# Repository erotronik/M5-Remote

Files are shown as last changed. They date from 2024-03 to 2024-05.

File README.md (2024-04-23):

# M5 REMOTE

Please note that this is a modification of the OSSM-M5-Remote project by Ortlof, which is available at [https://github.com/ortlof/OSSM-M5-Remote](https://github.com/ortlof/OSSM-M5-Remote).

Also note that this is an early prototype that is not tested.

This modified project adds RGB Rotary encoders that can light the knobs, and allows the installation of an LED in the push-button.

Furthermore, communication with the board is switched to I2C, using a PWM controller for the LEDs and a port expander for the Rotary encoders. Note that this means that this modification is *not compatible* with the software written for the original OSSM M5 Remote. Currently, there only is a skeleton project [that sketches how to interface with the components on the board in the Firmware folder](./Firmware).

The modified PCB design can be found in the `Hardware/PCB` folder.

The remaining folders in this project are unchanged - please note that the software contained in this repository will not work with the changed hardware.

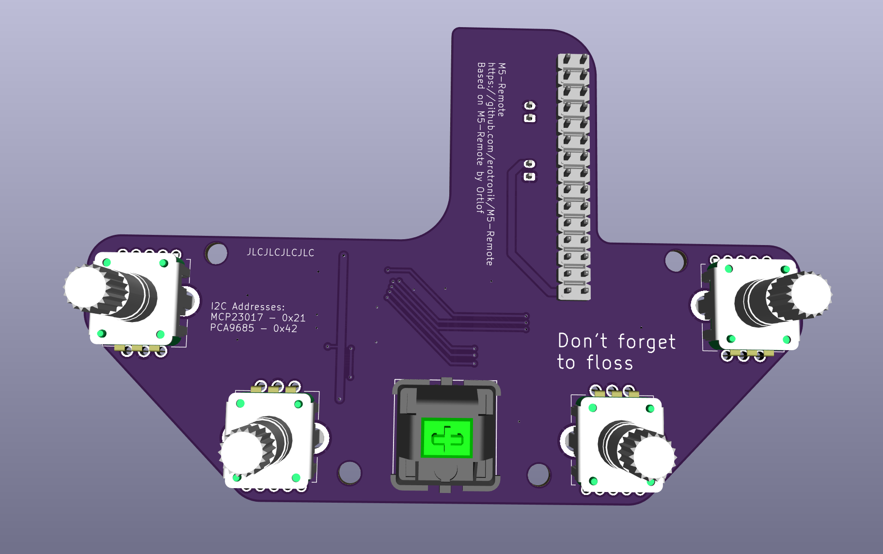
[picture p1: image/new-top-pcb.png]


## Overview of the M5-Remote

The M5 Remote is a remote control platform, e.g. for Sex Toys, or estim devices.

The original project was developed for the OSSM project (https://github.com/KinkyMakers/OSSM-hardware).

This modified version currently does not have direct support for any toys, and requires you to write your own software.

To help with development and design join the KinkyMakers Discord: https://discord.gg/MmpT9xE . Be sure to say hello in the #m5-remote channel. 

# Build the M5 Remote Yourself

## PCB from JLCPCB

The PCB is designed to be made using the JLCPCB assembly service.

To order the PCB, go to [JLCPCP](https://jlcpcb.com) and upload the gerber zip contained in `PCB/jlcpcb`. Leave all settings at default - you can change the PCB colour if you want.

Enable "PCB" assembly, and choose "assemble bottom side" (not selected by default).

In the next step, upload `bom.csv` and `positions.csv`. Verify that the positioning of the components looks corerct before ordering.

## Bill Of Materials for sourcing Electrical Components

BOM is on Octopart for Easy Sourcing: https://octopart.com/bom-tool/pqx0O8QI

## Additional parts needed that are not found on Octopart:

Note - instead of the Kailh switches from pimoroni, any Cherry-compatible switch with LED hole can be used.

| Quantity | Part | Sourcing EU | Price € |
|---|---|---|---|
| 1x | Switch | https://shop.pimoroni.com/products/kailh-mechanical-switches-pack-of-12?variant=32056315314259 | 7
| 2x | M3x25mm Hex Head Cap Bolt | https://www.amazon.de/Edelstahl-Innensechskant-Bolzenset-Eisenrahmen-Mechanischer-Innensechskantschraube-Mutternset/dp/B07PPFT871/ | 12,97 € |
| 4x | M3x20mm Hex Head Cap Bolt | Comes as part of the set mentioned above | " | 
| 4x | Heat Set inserts M3 | https://www.amazon.de/ruthex-Gewindeeinsatz-St%C3%BCck-Gewindebuchsen-Kunststoffteile/dp/B08BCRZZS3 | 8,99 € |
| 1x | 3,7v 2000mAh Lipo Batterie Size 34,5 mm x 10,6 mm x 56 mm | https://www.amazon.de/EEMB-103454-2AhLithium-Schutzplatine-Isolationsbeschichtung/dp/B08214DJLJ/ | 14,89 € |

--------------------------------------------

| Quantity | Part | Sourcing US | Price $ |
|---|---|---|---|
| 2x | M3x25mm Hex Head Cap Bolt | https://www.amazon.com/dp/B09NR8X2LV | $17.99 |
| 4x | M3x20mm Hex Head Cap Bolt | Comes as part of the set mentioned above | " | 
| 4x | Heat Set inserts M3 | https://www.amazon.com/ruthex-M3-Threaded-Inserts-RX-M3x5-7/dp/B08BCRZZS3 | $10.99 |
| 1x | 3.7v 2000mAh Lipo Battery Size 34.5 X 56 X 10.6 mm (The wires will need to be reversed in the connector on this one! See Assembly instructions for more info.) | https://www.amazon.com/EEMB-2000mAh-Battery-Rechargeable-Connector/dp/B08214DJLJ/ | $14.99 |

## 3D Printed Parts Needed:

| Quantity | Part | Information |
|---|---|---|
| 1x | Bottom.stl or Bottom_Adafruit_LIPO.stl or Bottom-Magnets.stl| There is a specific version for the wider Adafruit LIPO battery. Print with the base side facing down, 6 walls 20% Infill | 
| 1x | TOP-*-Keycap-Standoff.stl | Top Depends on your Keycap: Cherry or DSA (DSA is wider) | 
| 4x | M5_Remote_Knob_Customizable.scad | If you go for the 3d Printed knobs |

Filament - A good quality PLA works well. While there are no threads it is recommended that your printer is well calibrated.  

# [Assembly instructions](Assembly.md)

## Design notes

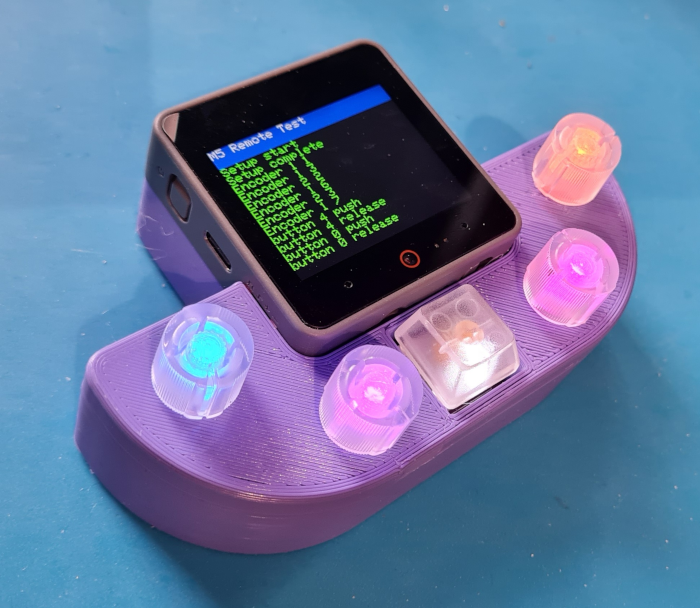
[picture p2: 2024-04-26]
image/remote.png

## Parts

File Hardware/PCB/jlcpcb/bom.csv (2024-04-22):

Designator | Footprint | Quantity | Value | LCSC Part #
C1, C2 | 0402 | 2 | 100n | C1525
R1, R10, R11, R13, R14, R15, R17, R2, R3, R5, R6, R7, R9 | 1206 | 13 | 120R | C17909
R12, R16, R18, R19, R4, R8 | 1206 | 6 | 4k7 | C17936
U1 | TSSOP-28_4.4x9.7mm_P0.65mm | 1 | PCA9685PW | C2678753
U2 | SSOP-28_5.3x10.2mm_P0.65mm | 1 | MCP23017_SS | C506653

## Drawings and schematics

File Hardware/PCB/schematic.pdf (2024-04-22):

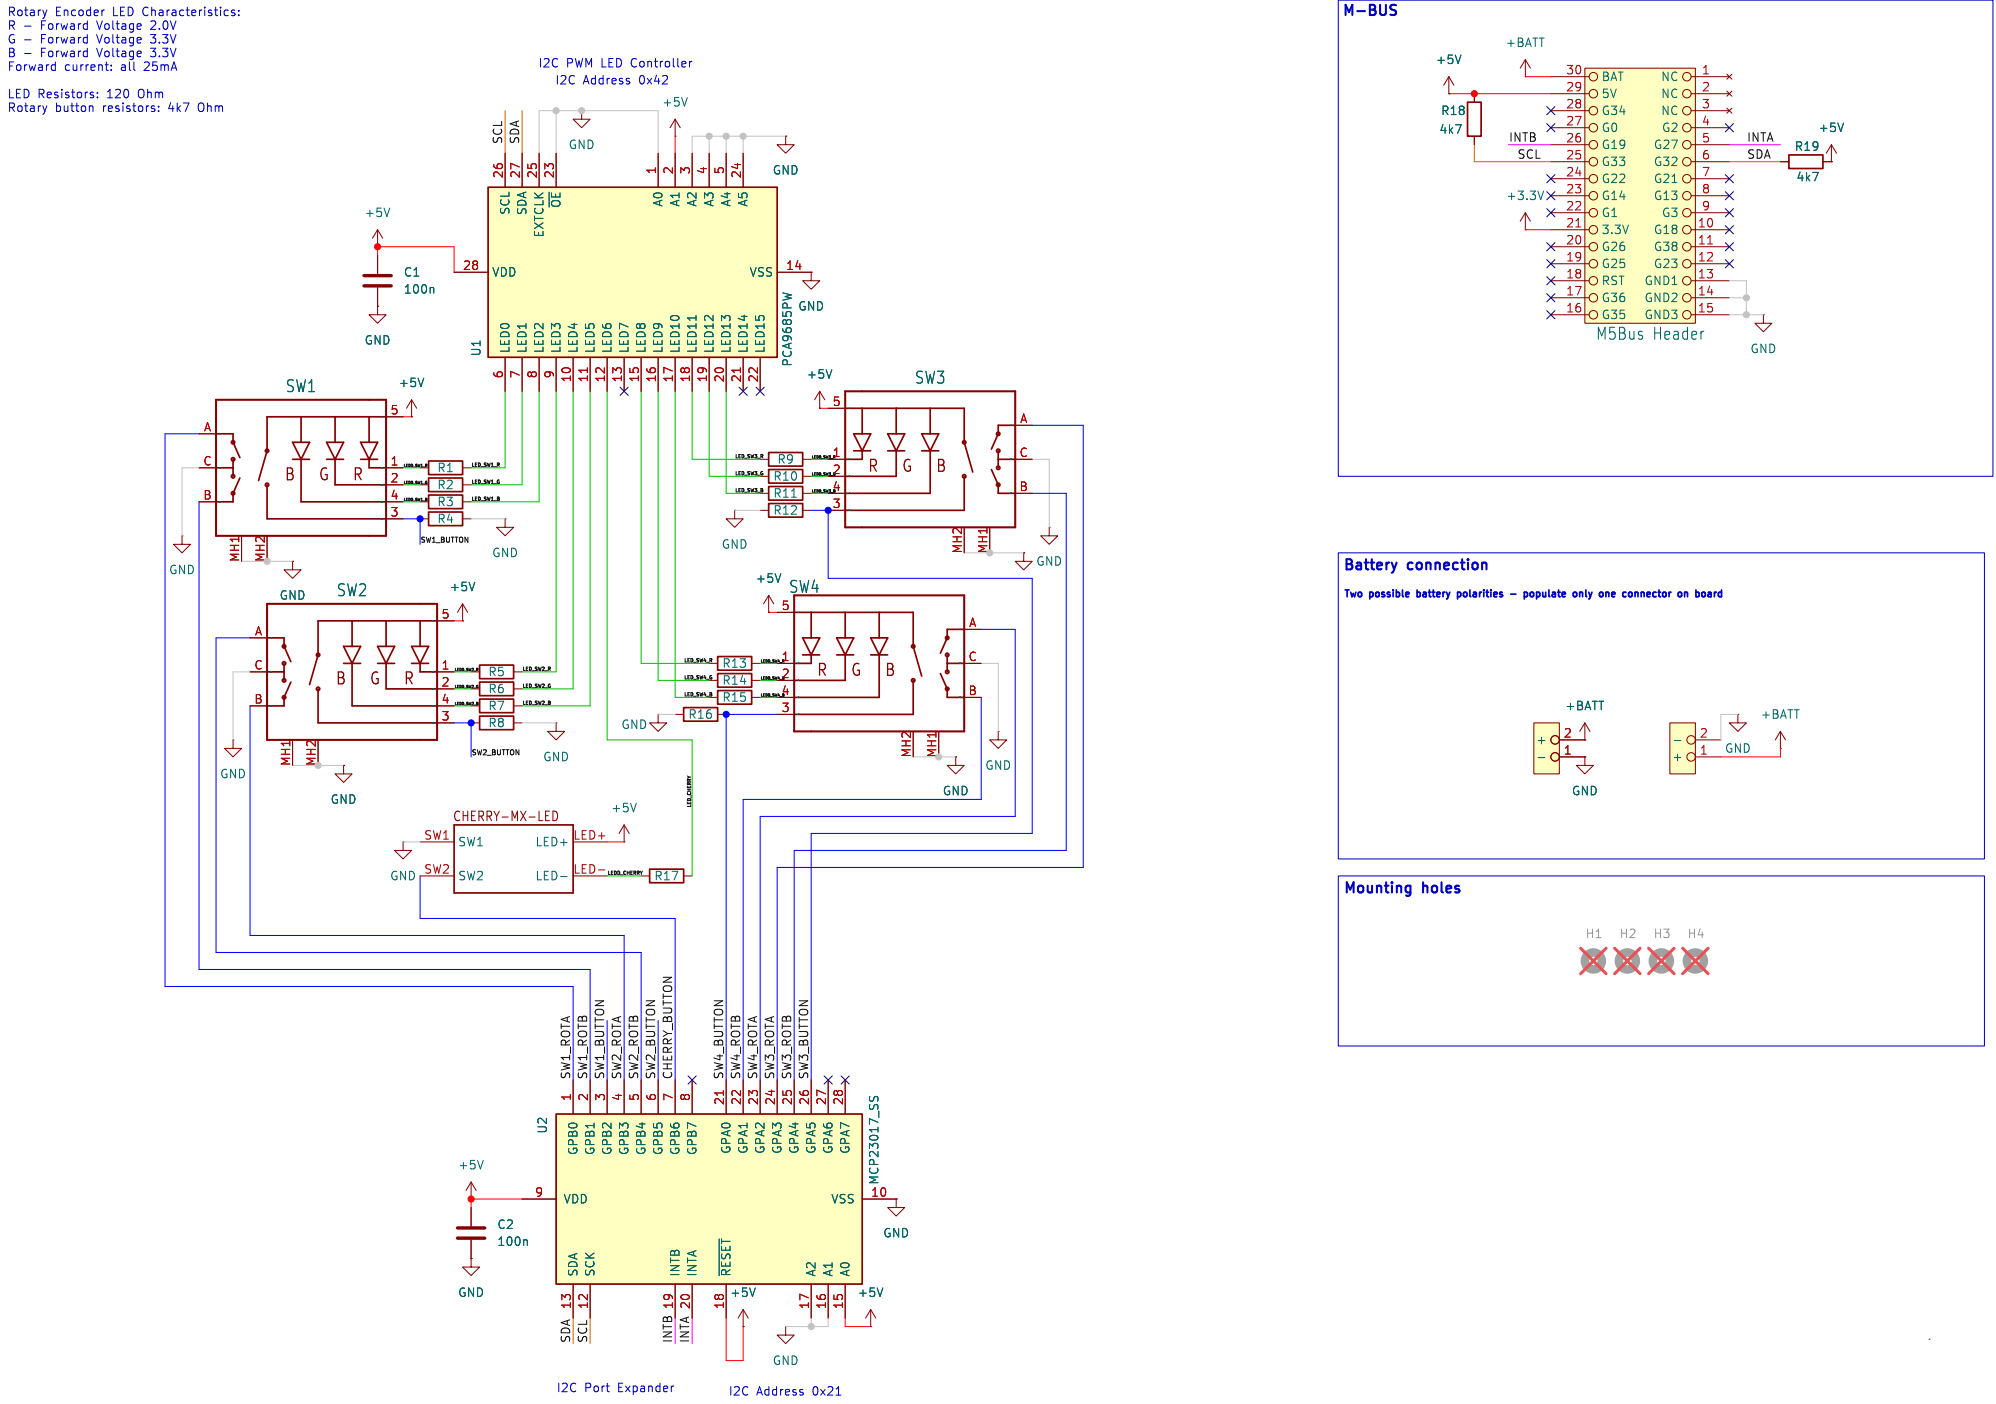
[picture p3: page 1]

Rotary Encoder LED Characteristics: R - Forward Voltage 2.0V G - Forward Voltage 3.3V
+5V GND

2 LED13 20 LED14 21 LED15 22 ~{OE}23 A5 24 EXTCLK 25 SCL 26 SDA 27 VDD 28 A2

1 VSS 10 SCK 12 SDA 13 A0 15 A1 16 A2 17 ~{RESET} 18 INTB 19 GPB1

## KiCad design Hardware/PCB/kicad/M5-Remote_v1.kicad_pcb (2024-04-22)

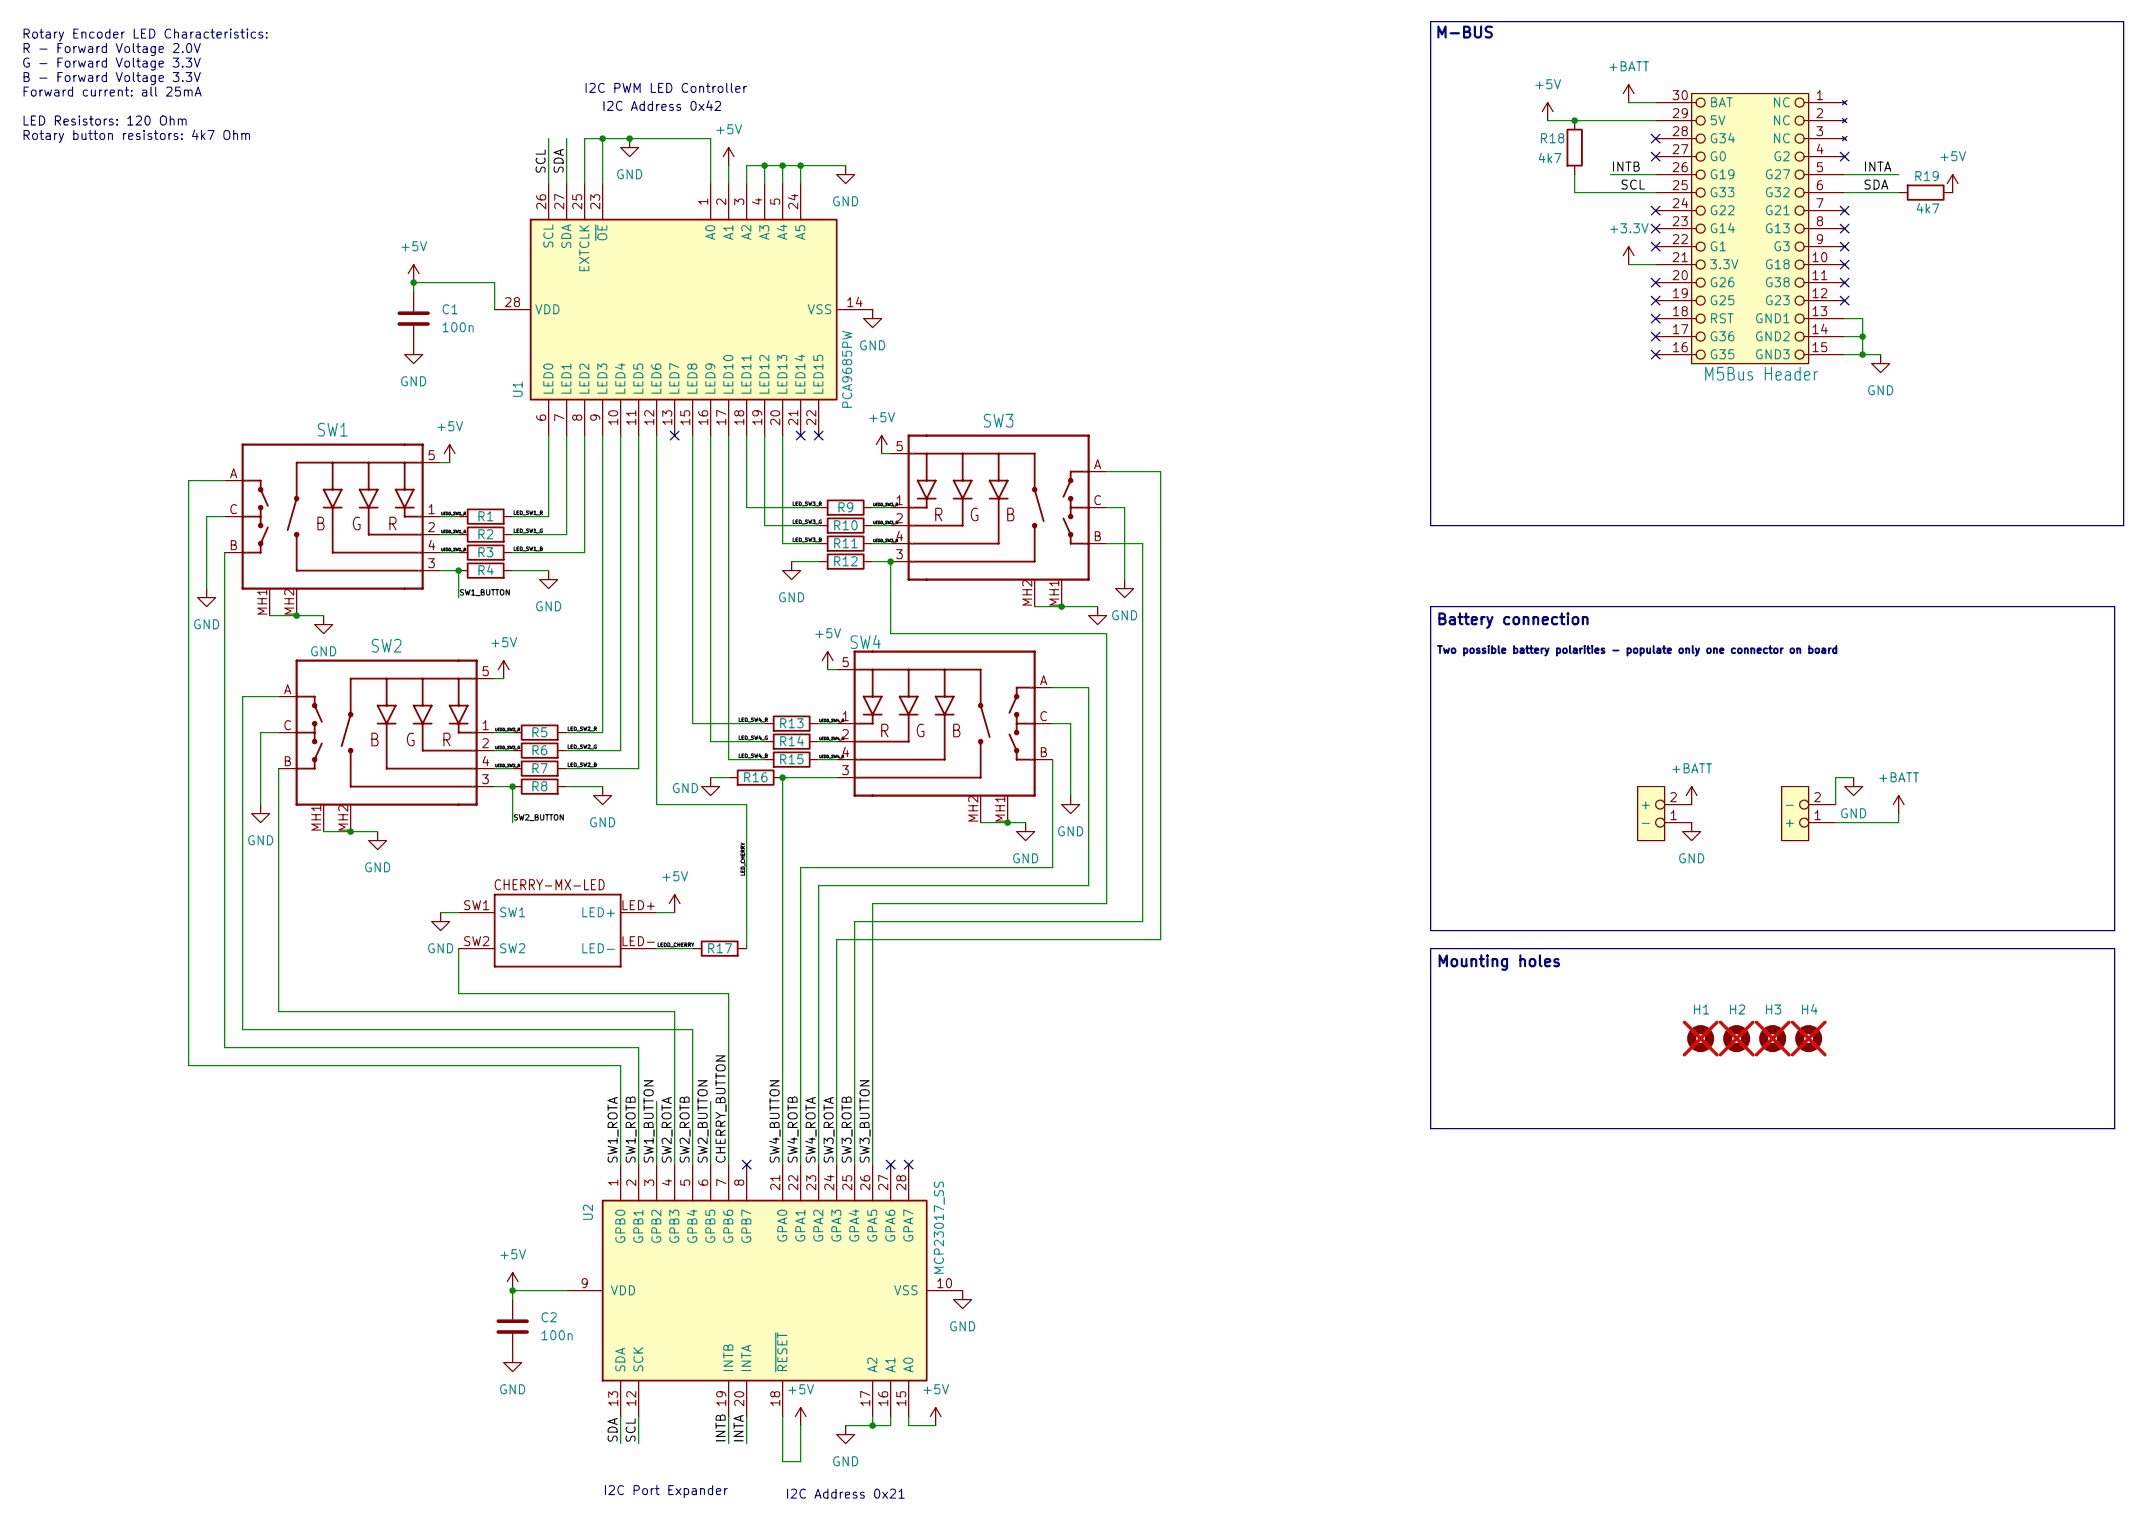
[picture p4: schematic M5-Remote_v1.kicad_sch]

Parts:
B1, B2: JST-PH-2MM,180; JST_PH_S2B-PH-K_1x02_P2.00mm_Horizontal
C1, C2: 100n; C_0402_1005Metric; MFR Part Number CL05B104KO5NNNC; LCSC Part # C1525
H1, H2, H3, H4: MountingHole; mounting_hole_3.3mm; not fitted
M5-CORE2: M5Bus Header; M5_CORE2; MFR Part Number 10129381-930001BLF
R1, R2, R3, R5, R6, R7, R9, R10, R11, R13, R14, R15, R17: 120R; R_1206_3216Metric; MFR Part Number 1206W4F1200T5E; LCSC Part # C17909
R4, R8, R12, R16, R18, R19: 4k7; R_1206_3216Metric; MFR Part Number 1206W4F4701T5E; LCSC Part # C17936
SW1, SW2, SW3, SW4: PEL12T4225SS1024; MFR Part Number PEL12T4225SS1024
U1: PCA9685PW; TSSOP-28_4.4x9.7mm_P0.65mm; MFR Part Number PCA9685; LCSC Part # C2678753
U2: MCP23017_SS; SSOP-28_5.3x10.2mm_P0.65mm; MFR Part Number MCP23017-E/SS; LCSC Part # C506653
U3: CHERRY-MX-LED

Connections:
+3.3V: M5-CORE2.21 (3.3V)
+5V: C1.1, C2.1, M5-CORE2.29 (5V), R18.1, R19.1, SW1.5 (+), SW2.5 (+), SW3.5 (+), SW4.5 (+), U1.2 (A1), U1.28 (VDD), U2.9 (VDD), U2.15 (A0), U2.18 (~RESET), U3.LED+
+BATT: B1.2 (+), B2.1 (+), M5-CORE2.30 (BAT)
/CHERRY_BUTTON: U2.7 (GPB6), U3.SW2
/INTA: M5-CORE2.5 (G27), U2.20 (INTA)
/INTB: M5-CORE2.26 (G19), U2.19 (INTB)
/LEDD_CHERRY: R17.1, U3.LED-
/LEDD_SW1_B: R3.1, SW1.4 (-B)
/LEDD_SW1_G: R2.1, SW1.2 (-G)
/LEDD_SW1_R: R1.1, SW1.1 (-R)
/LEDD_SW2_B: R7.1, SW2.4 (-B)
/LEDD_SW2_G: R6.1, SW2.2 (-G)
/LEDD_SW2_R: R5.1, SW2.1 (-R)
/LEDD_SW3_B: R11.1, SW3.4 (-B)
/LEDD_SW3_G: R10.1, SW3.2 (-G)
/LEDD_SW3_R: R9.1, SW3.1 (-R)
/LEDD_SW4_B: R15.1, SW4.4 (-B)
/LEDD_SW4_G: R14.1, SW4.2 (-G)
/LEDD_SW4_R: R13.1, SW4.1 (-R)
/LED_CHERRY: R17.2, U1.12 (LED6)
/LED_SW1_B: R3.2, U1.8 (LED2)
/LED_SW1_G: R2.2, U1.7 (LED1)
/LED_SW1_R: R1.2, U1.6 (LED0)
/LED_SW2_B: R7.2, U1.11 (LED5)
/LED_SW2_G: R6.2, U1.10 (LED4)
/LED_SW2_R: R5.2, U1.9 (LED3)
/LED_SW3_B: R11.2, U1.20 (LED13)
/LED_SW3_G: R10.2, U1.19 (LED12)
/LED_SW3_R: R9.2, U1.18 (LED11)
/LED_SW4_B: R15.2, U1.17 (LED10)
/LED_SW4_G: R14.2, U1.16 (LED9)
/LED_SW4_R: R13.2, U1.15 (LED8)
/SCL: M5-CORE2.25 (G33), R18.2, U1.26 (SCL), U2.12 (SCK)
/SDA: M5-CORE2.6 (G32), R19.2, U1.27 (SDA), U2.13 (SDA)
/SW1_BUTTON: R4.1, SW1.3 (SW), U2.3 (GPB2)
/SW1_ROTA: SW1.A, U2.1 (GPB0)
/SW1_ROTB: SW1.B, U2.2 (GPB1)
/SW2_BUTTON: R8.1, SW2.3 (SW), U2.6 (GPB5)
/SW2_ROTA: SW2.B, U2.4 (GPB3)
/SW2_ROTB: SW2.A, U2.5 (GPB4)
/SW3_BUTTON: R12.1, SW3.3 (SW), U2.26 (GPA5)
/SW3_ROTA: SW3.A, U2.24 (GPA3)
/SW3_ROTB: SW3.B, U2.25 (GPA4)
/SW4_BUTTON: R16.1, SW4.3 (SW), U2.21 (GPA0)
/SW4_ROTA: SW4.A, U2.23 (GPA2)
/SW4_ROTB: SW4.B, U2.22 (GPA1)
GND: B1.1 (-), B2.2 (-), C1.2, C2.2, M5-CORE2.13 (GND1), M5-CORE2.14 (GND2), M5-CORE2.15 (GND3), R4.2, R8.2, R12.2, R16.2, SW1.C, SW1.MH1, SW1.MH2, SW2.C, SW2.MH1, SW2.MH2, SW3.C, SW3.MH1, SW3.MH2, SW4.C, SW4.MH1, SW4.MH2, U1.1 (A0), U1.3 (A2), U1.4 (A3), U1.5 (A4), U1.14 (VSS), U1.23 (~OE), U1.24 (A5), U1.25 (EXTCLK), U2.10 (VSS), U2.16 (A1), U2.17 (A2), U3.SW1

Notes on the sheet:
I2C Address 0x21
I2C Address 0x42
Mounting holes
I2C PWM LED Controller
Battery connection
Rotary Encoder LED Characteristics: R - Forward Voltage 2.0V G - Forward Voltage 3.3V B - Forward Voltage 3.3V Forward current: all 25mA LED Resistors: 120 Ohm Rotary button resistors: 4k7 Ohm
Two possible battery polarities - populate only one connector on board
M-BUS
I2C Port Expander

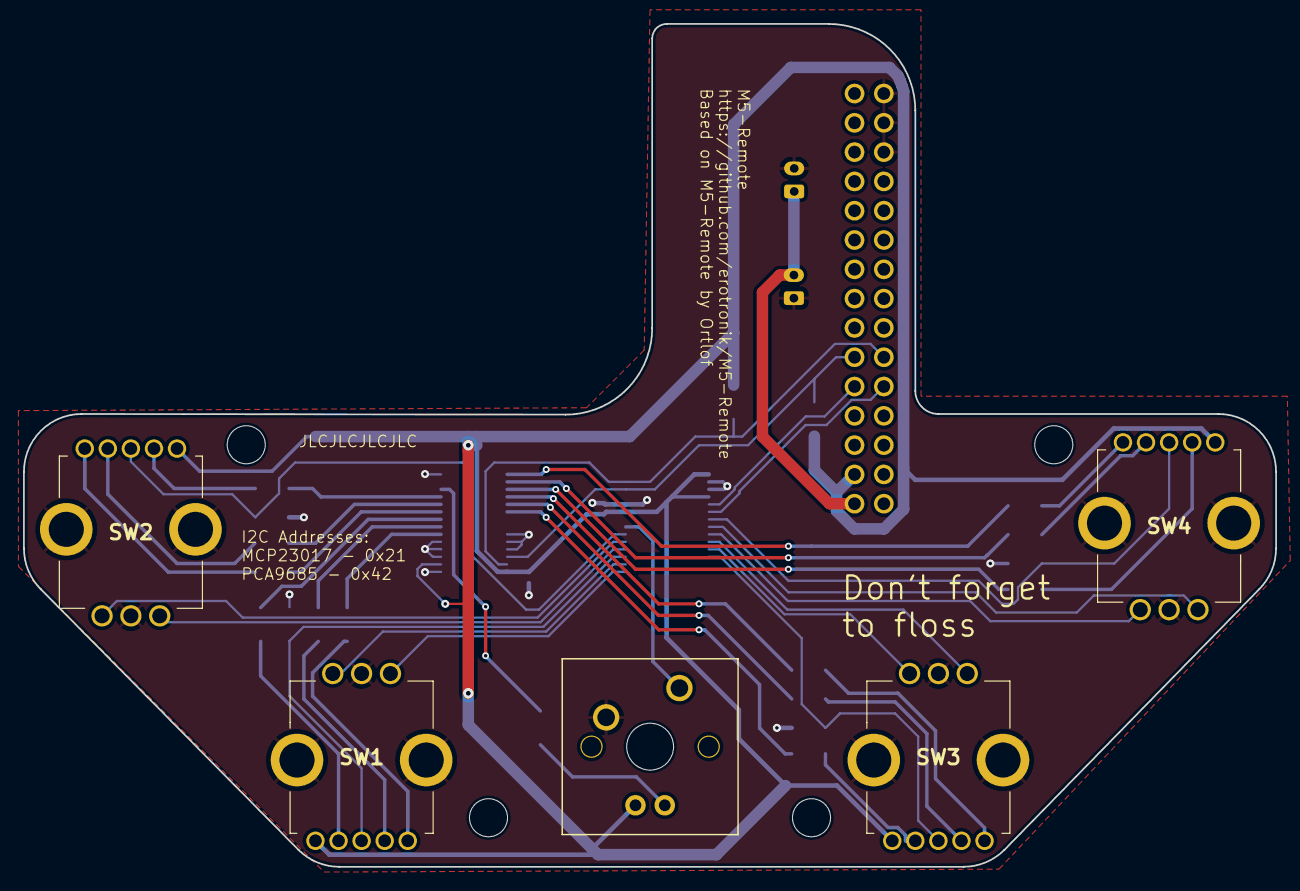
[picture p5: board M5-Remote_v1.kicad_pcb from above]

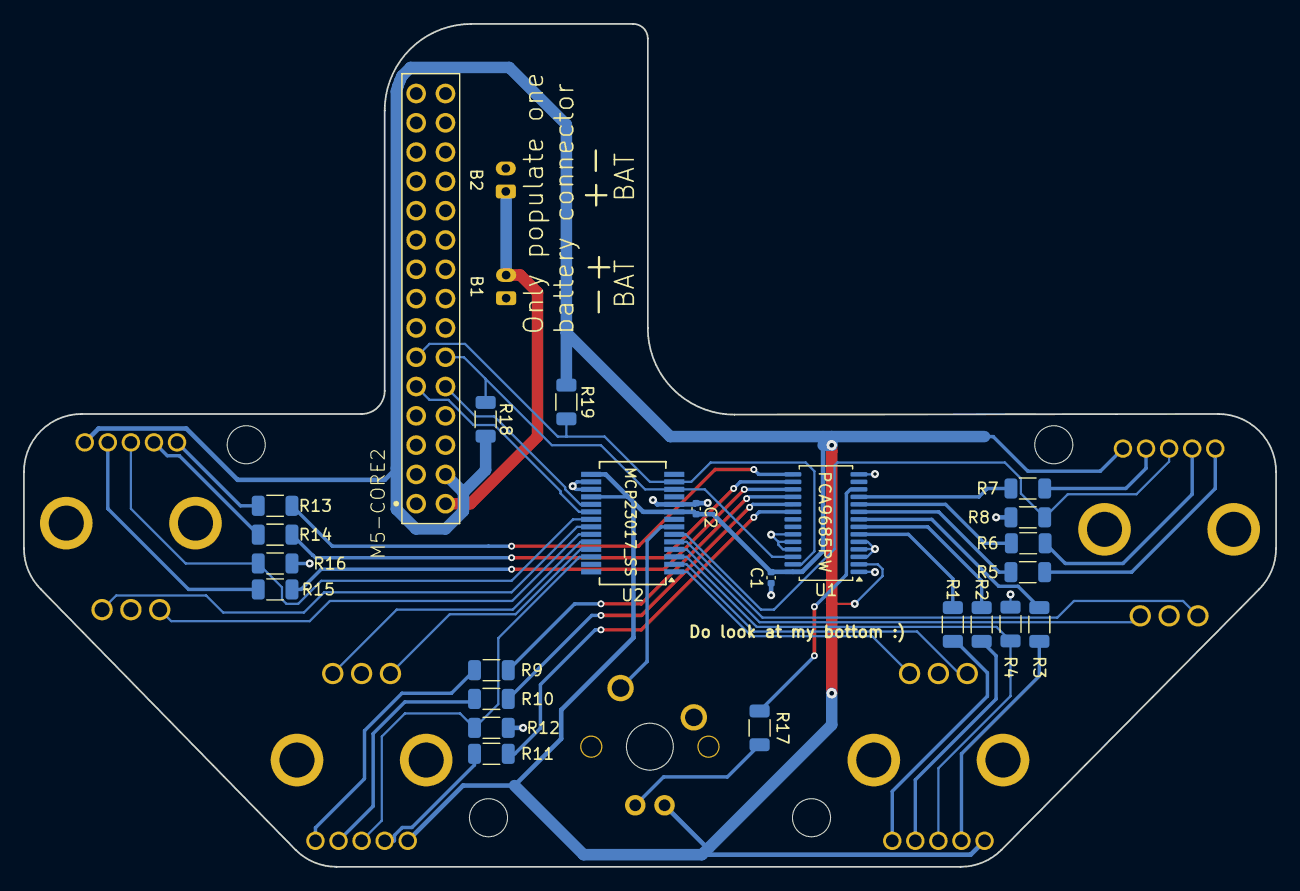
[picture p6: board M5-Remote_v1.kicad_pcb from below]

Board: 2 copper layers, 108.5 x 73.1 mm, 35 parts (26 on the bottom side), 46 nets.

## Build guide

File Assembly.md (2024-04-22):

# Assembling the M5 Remote

**Some important notes**

* Due to a lack of standardisation in LIPO battery polarity it is important to verify how yours is configured. If the battery is reversed it will result in the CORE M5 Stack being damaged.

## Solder the components

1. Place the encoders (Bourns  PEL12T-4225S-S1024) at SW1, SW2, SW3, and SW4 and solder them to the board.

2. The Cherry switch is soldered to the center position in the white square. After soldering the switch, add an LED to the switch if desired.

3. Next, the headers. Insert the headers from the front of the PCB (Amphenol Communications Solution 10129381-930001BLF), and solder each pin to the board.  

4. Finally we will solder the battery connector (JST S2B-PH-K-S(LF)(SN)) on the back side of the PCB. Choose one of the two possible locations depending on the polarity of the your battery.

5. Again pay special attention to the polarity of the Lithum battery you have, checking to see if the negative terminal of the battery connector will align with the negative pin of the connector on the PCB.

## 3D printed parts

All parts are printed with 6 walls and 20% infill with a .04 nozzle. No supports and no brim (just a skirt).

A good quality PLA works well. While there are no threads it is recommended that your printer is well calibrated.  

* Be sure to choose the correct back to print based on the battery that you source 

    USA - Adafruit 485-2011 / or [Alternate](https://www.amazon.com/EEMB-2000mAh-Battery-Rechargeable-Connector/dp/B08214DJLJ/) uses 'Bottom_Adafruit_Lipo.stl' OR you can use 'Bottom-Magnets.stl' if you want to add 6 x 3mm magnets.

    Other countries - [RS Pro 1449405](https://uk.rs-online.com/web/p/speciality-size-rechargeable-batteries/1449405) uses 'Bottom.stl', or if you want to use magnets in the base you can use 'Bottom-Magnets.stl' that will accept 6 x 3mm magnets.

* You have options for the top depending on the keycap type you choose (cherry vs DSA). 

    If you chose to buy a DSA keycap go with 'TOP-DSA-Keycap-Standoff_Bigger_Ecoder_Space.stl'

    If you chose to buy a Cherry Keycap go with 'TOP-Cherry-Keycap-Standoff_Bigger_Ecoder_Space.stl'

* You can print encoder knobs or purchaes separate ones, 'M5_Remote_Knob_Customizable.scad'

* If you would like to mount the OSSM M5 remote to a mini tripod you can print the excellent holder by KinkyMakers Discord community member GHHOSS, the file is called  'M5_Tripod_Holder_v3.stl' and can be found in the 'GHHOSS_tripod_mount' folder.

* Finally you will add the M3 brass heatset inserts to the underside of the **TOP** piece.

## Final Assembly

1. Remove the M5 Core2 MIC/MPU Module from M5 Core2 Bottom, then unscrew the grey bottom and remove internal battery. Store the screws, the back and battery somewhere in case you want to use the M5 Stack Core2 for another project later.

2. Affix the battery to the bottom case with double sided tape.



3. Connect Battery to PCB connector on the back side of the PCB.



4. Insert the PCB into Bottom case. 
AffixBattery

5. Connect the M5 Core2 to the headers on the PCB and fasten with two 25mm M3 Bolts to Case.



6. Put top on Remote and fasten with four M3 20mm Bolts to the Case.



7. Install the Mx Cap and Encoder Knobs.

8. Charge the battery fully.

## Upload Software

To use this project, you currently have to write your own software. The i2c addresses of the components are provided on the board and schematic.

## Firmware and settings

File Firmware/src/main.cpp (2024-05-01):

#include <Arduino.h>
// #include <M5Unified.h>
#include <M5CoreS3.h>
#include <atomic>
#include <FastLED.h>
#include "m5io.h"

void printf_log(const char *format, ...);

byte buttonhue[] = {0, 64, 128, 192, 0};

byte lastencodertest[numencoders] = {0};
byte encodertest[numencoders] = {0};

void RotaryEncoderChanged(bool clockwise, int id) {
  if (clockwise) {
    encodertest[id]++;
  } else {
    encodertest[id]--;
  }
}

M5Canvas canvas(&CoreS3.Display);
M5Canvas titlecanvas(&CoreS3.Display);

int canvasy;

void setup() {
  auto cfg = M5.config();
  cfg.serial_baudrate = 115200;
  CoreS3.begin(cfg);

  titlecanvas.createSprite(CoreS3.Display.width(), 40);
  titlecanvas.setColorDepth(8);
  titlecanvas.setTextColor(WHITE,BLUE);
  titlecanvas.setTextSize(2);
  titlecanvas.fillSprite(BLUE);
  titlecanvas.println("M5 Remote Test");
  titlecanvas.pushSprite(0,0);
  canvasy = titlecanvas.fontHeight()*2;

  canvas.setColorDepth(1);
  canvas.createSprite(CoreS3.Display.width(), CoreS3.Display.height()-canvasy);
  canvas.setPaletteColor(1, GREEN);
  canvas.setTextSize((float)canvas.width() / 160);
  canvas.setTextScroll(true);
  canvas.pushSprite(0,canvasy);
  
  Wire.begin();

  pinMode(INTA, INPUT_PULLUP);
  pinMode(INTB, INPUT_PULLUP);

  delay(500); // give serial time to catch up
  printf_log("Setup start\n");

  m5io_init();

  printf_log("Setup complete\n");
}

void handlebuttonpushes() {
  for (int i=0; i< numbuttons; i++) {
    if (buttonpressedflags[i]) {
      printf_log("button %d %s\n", i, lastbuttonstates[i]?"push":"release");
      buttonpressedflags[i] = false;
      if (lastbuttonstates[i]) 
        buttonhue[i] = 0;
    }
  }
}

void handlerotaryencoders() {
  for (int i=0; i < numencoders; i++) {
    if (encodertest[i] != lastencodertest[i]) {
      printf_log("Encoder %d %d\n", i, encodertest[i]);
      lastencodertest[i] = encodertest[i];
    }
  }
}

void setleds() {
  for (int i=0; i<4; i++) {
    m5io_showanalogrgb(i+1, CHSV(buttonhue[i],255,255)); // rotary LED
    buttonhue[i]++;
  }
  m5io_showanalogrgb(5, CHSV(255,255,buttonhue[4]/2)); // cherry LED (very bright)
  buttonhue[4]++;
}

void loop() {
  handlebuttonpushes();
  handlerotaryencoders();
  setleds();
  delay (20);
}

void printf_log(const char *format, ...) {
    static char buf[256];
    va_list args;
    va_start(args, format);
    vsnprintf(buf, 255, format, args);
    va_end(args);
    Serial.print(buf);
    canvas.printf(buf);
    canvas.pushSprite(0, canvasy);
}

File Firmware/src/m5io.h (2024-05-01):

#ifndef SRC_M5IO_H_
#define SRC_M5IO_H_

#include "Rotary.h"
#include "RotaryEncOverMCP.h"
#include "PCA9685.h"

void printf_log(const char *format, ...);

//void RotaryEncoderChanged(bool clockwise, int id);

// MCP23017 is port expander on I2C x021 and INT on pin 6/7 (different if not CoreS3)
//
// b0 is sw1_rota b1 is sw1_rotb, b2 = sw1_button
// b3 is sw2_rota b4 is sw2_rotb, b5 = sw2_button
// b6 = cherry button
// a0 is sw4_button, a1 is sw4_rotb, a2 = sw4_rota
// a3 is sw3_rota, a4 is sw3_rotb, a5 = sw3_button

Adafruit_MCP23X17 mcp;
constexpr uint8_t INTA = 6;
constexpr uint8_t INTB = 7;
const byte buttonpins[] = {10, 13, 5, 0, 14};
const byte numbuttons = sizeof(buttonpins);

// semaphore for reading of the rotary encoder 
SemaphoreHandle_t rotaryISRSemaphore = nullptr;

RotaryEncOverMCP rotaryEncoders[] = {
  RotaryEncOverMCP(&mcp, 9, 8, &RotaryEncoderChanged, 0),
  RotaryEncOverMCP(&mcp, 11,12, &RotaryEncoderChanged, 1),
  RotaryEncOverMCP(&mcp, 4, 3, &RotaryEncoderChanged, 2),
  RotaryEncOverMCP(&mcp, 1, 2, &RotaryEncoderChanged, 3)
};
const byte numencoders = 4;

// PWM controller is PCA9685PW on 0x42
//
// LED0 is R on SW1, LED1 is G on SW1, LED2 is B on SW1
// LED3 is R on SW2, LED4 is G on SW2, LED5 is B on SW2
// LED11 is R on SW3, LED12 is G on SW3, LED13 is B on SW3
// LED8 is R on SW4, LED9 is G on SW4, LED10 is B on SW4
// LED6 is Cherry LED

PCA9685 PCA(0x42);

// Switch number 1-4 (5 for cherry, single LED), and CRGB structure from FastLED

void m5io_showanalogrgb(byte sw, const CRGB& rgb) { 
  static byte pinstarts[] = {0,3,11,8, 6};
  byte base = pinstarts[sw-1];
  PCA.setPWM(base, rgb.r*16);
  if (sw != 5) {
    PCA.setPWM(base+1, rgb.g*16);  // FastLED is 8 bit, PCA is 12 bit
    PCA.setPWM(base+2, rgb.b*16);
  }
}

volatile bool buttonpressedflags[numbuttons] = {false};
bool lastbuttonstates[numbuttons] = {false};
static unsigned long lastbuttondebounce[numbuttons] = {0};

void handlemcpinterrupt() {
  auto data = mcp.getCapturedInterrupt();

  // check for rotary encoder change
  for (int i=0; i < numencoders; i++) {
     rotaryEncoders[i].feedInput(data);
  }
  // check for button change
  unsigned long now = millis();
  for (byte i=0; i< numbuttons; i++) {
    if (now - lastbuttondebounce[i] > 10) { // debounce time
      byte result = (data >> buttonpins[i]) &1;
      if (buttonpins[i] == 14) result = !result; // cherry is inverted
      if (result != lastbuttonstates[i]) {
        buttonpressedflags[i] = true;
        lastbuttonstates[i] = result;
        lastbuttondebounce[i] = now;
      }
    }
  }
  mcp.clearInterrupts();
}

void rotaryReaderTask(void* pArgs) {
  (void)pArgs;
  while(true) {
    if(xSemaphoreTake(rotaryISRSemaphore, portMAX_DELAY) == pdPASS) {
      handlemcpinterrupt();
    }
  }
}

// Interrupt from MCP means a button or rotary encoder changed

void IRAM_ATTR intactive() {
  BaseType_t xHigherPriorityTaskWoken = pdFALSE;
  xSemaphoreGiveFromISR(rotaryISRSemaphore, &xHigherPriorityTaskWoken);
  if(xHigherPriorityTaskWoken) {
      portYIELD_FROM_ISR ();
  } 
}

void m5io_init(void) {
  //initialize semaphore for reader task
  rotaryISRSemaphore = xSemaphoreCreateBinary();

  if ( ! PCA.begin(PCA9685_MODE1_AUTOINCR | PCA9685_MODE1_ALLCALL, PCA9685_MODE2_INVERT) ) {
    printf_log("No PCA9685 found");
    while (1) {}
  }

  for (byte i = 0; i<32; i++) {
    for (byte led = 0; led<15; led++)
      PCA.setPWM(led, 2048 - (i*64));
    delay(20);
  }  // acts as a delay between setup too

  if ( ! mcp.begin_I2C(0x21) ) {
    printf_log("No MCP23X17 found");
    while (1) {}
  }

  mcp.setupInterrupts(false, true, HIGH);

  for ( byte i = 0; i <=15; ++i ) {
    if (i==0 || i== 5 || i ==10 || i ==13)
      mcp.pinMode(i, INPUT); 
    else
      mcp.pinMode(i, INPUT_PULLUP);
  }
  for (byte pin=0;pin<16;pin++) 
    mcp.setupInterruptPin(pin, CHANGE);

  for (byte i=0; i<numencoders; i++)
    rotaryEncoders[i].init();  // currently a NOP

  xTaskCreate(&rotaryReaderTask, "io reader", 2048, NULL, 20, NULL);
  attachInterrupt(digitalPinToInterrupt(INTA), intactive, FALLING);
  attachInterrupt(digitalPinToInterrupt(INTB), intactive, FALLING);

  Serial.printf("GPIO A 0: %d\n", mcp.readGPIOA()); // no interrupts unless you do a mcp.readGPIOA();
}


#endif

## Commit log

2024-02-12 Add current version and eagle exports
    [OSSM-M5-Remote_v1.brd, OSSM-M5-Remote_v1.sch]
2024-02-12 kicad import
    [OSSM-M5-Remote_v1.kicad_pcb, OSSM-M5-Remote_v1.kicad_sch]
2024-02-16 Update schematic, remove traces
    [OSSM-M5-Remote_v1.kicad_pcb, OSSM-M5-Remote_v1.kicad_sch]
2024-03-21 Cleaner schematic
    [OSSM-M5-Remote_v1.kicad_pcb, OSSM-M5-Remote_v1.kicad_sch]
2024-03-22 Starting routing
    [OSSM-M5-Remote_v1.kicad_pcb, OSSM-M5-Remote_v1.kicad_sch]
2024-03-22 Everything connected
    [OSSM-M5-Remote_v1.kicad_pcb, OSSM-M5-Remote_v1.kicad_sch]
2024-03-26 PCB updates
    [OSSM-M5-Remote_v1.kicad_pcb, OSSM-M5-Remote_v1.kicad_sch]
2024-03-26 Big rename
    [M5-Remote_v1.kicad_pcb, M5-Remote_v1.kicad_sch]
2024-03-27 Final touches for first PCB version
    [M5-Remote_v1.kicad_pcb, M5-Remote_v1.kicad_sch]
2024-04-22 Tiny fix
    [M5-Remote_v1.kicad_pcb]
2024-04-22 Update readmes
    [M5-Remote_v1.kicad_pcb, M5-Remote_v1.kicad_sch]
2024-04-22 Remove source
    Does not work with this version of the hardware.
    [main.cpp]
2024-04-23 Add some sample code for the CoreS3 and the new hardware
2024-04-23 Don't enable the pullups on the switches for rotary encoders, they are already pull down
2024-04-23 A little cleanup ready to add some encoder handling
2024-04-23 Cleanup. Tell MCP to just mirror the interrupt to both pins so we can ignore one anyway
2024-04-23 Working with a thread
2024-04-23 No need to invert output from switches, remember to clear interrupts
    [main.cpp]
2024-04-26 Debounce time was causing some quick presses to be ignored, reduce it. Fix silly logic to something more simplest
    [main.cpp]
